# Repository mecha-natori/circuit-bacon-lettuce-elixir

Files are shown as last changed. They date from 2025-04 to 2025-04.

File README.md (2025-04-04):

# Bacon Lettuce Elixir

Bacon Lettuce ElixirはESP32-C3-WROOM-02を使用したBluetooth-USB変換基板です。

USB Type-Aのポートにそのまま差せるため、書き込み・給電が容易です。

## 仕様

| 機能 | 個数 | 備考 |
| :---: | ---: | :--- |
| MCU | 1 | ESP32-C3-WROOM-02 |
| UART | 1 | 電源ピンは5V・外部通信モジュール向け |
| USB Type-A メス | 1 | コントローラー接続用 |
| USB Type-A オス | 1 | 給電・書き込み用 |
| Bluetooth | 1 | MCU内蔵、Bluetooth 5 **(BLEのみ)** |
|  リセットスイッチ | 1 | |
| 5V-3.3Vレギュレータ | 1 | 外部電源からの供給用 |
| 寸法 | | 30mm x 50mm |

## 名前の由来

BLTからトマトが消えてエリクサーになったとさ。 **B**luetooth **L**ow **E**nergyです。

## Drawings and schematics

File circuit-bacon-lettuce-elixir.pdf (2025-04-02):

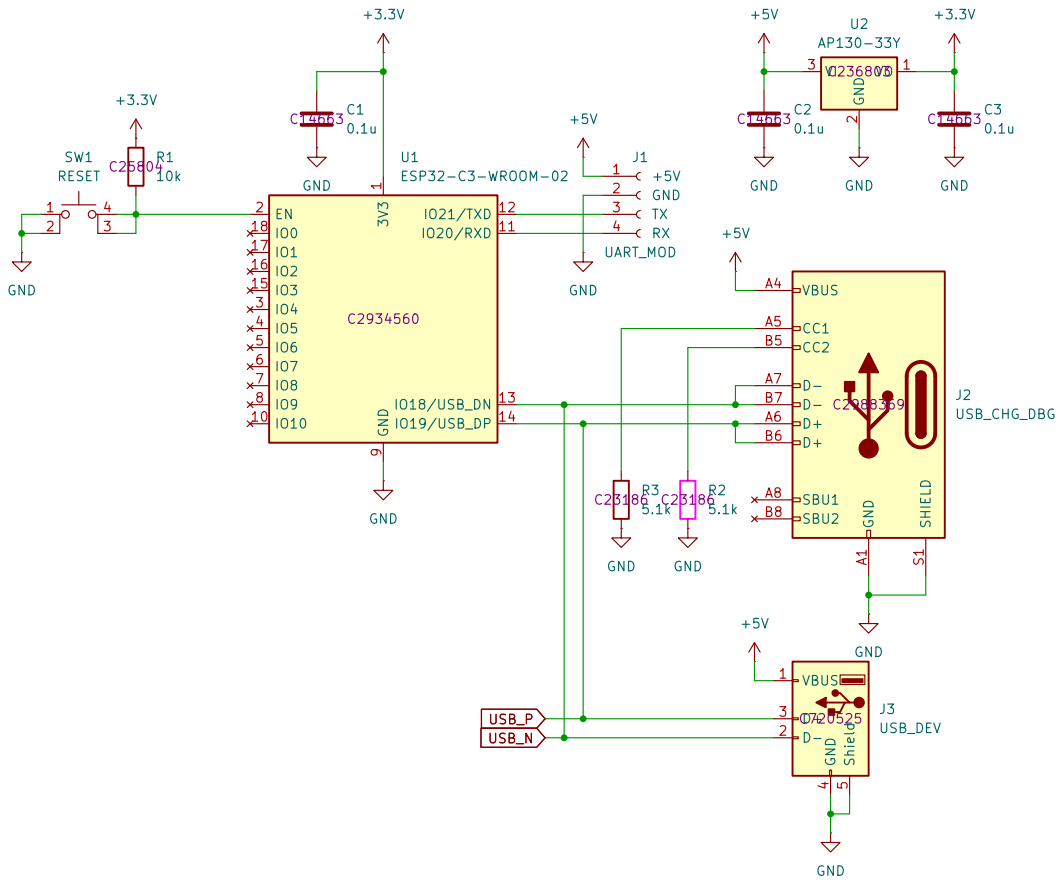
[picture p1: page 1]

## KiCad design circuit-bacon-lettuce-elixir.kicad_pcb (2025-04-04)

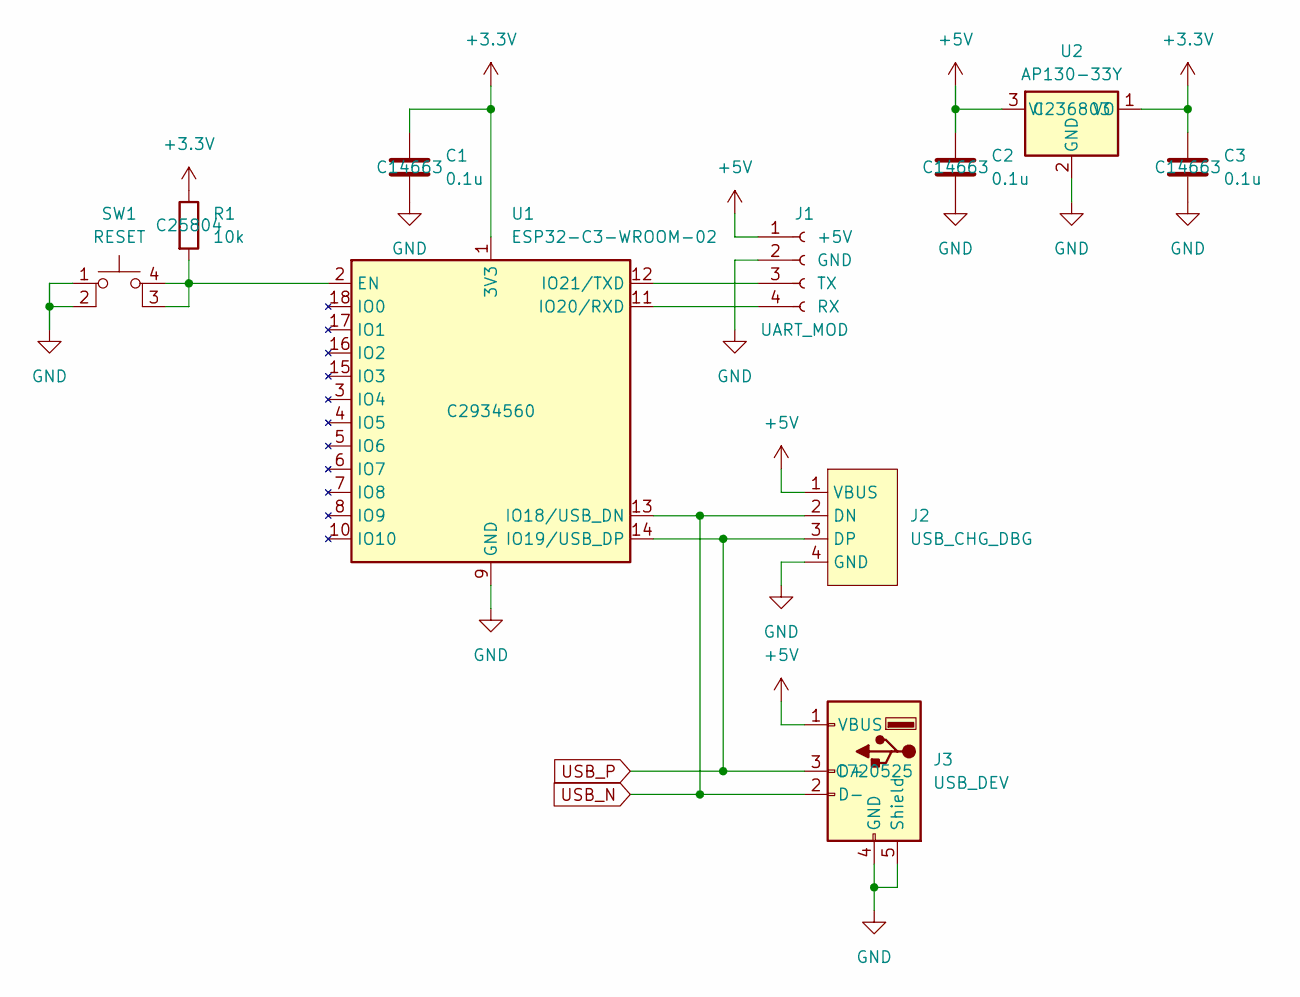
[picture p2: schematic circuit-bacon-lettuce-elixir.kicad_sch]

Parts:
C1, C2, C3: 0.1u; C_0603_1608Metric_Pad1.08x0.95mm_HandSolder; LCSC PN C14663
J1: UART_MOD; DF1B-4P-2.5DSA
J2: USB_CHG_DBG; PCB_USB_Connecter
J3: USB_DEV; USB_A_Receptacle_GCT_USB1046; LCSC PN C720525
R1: 10k; R_0603_1608Metric_Pad0.98x0.95mm_HandSolder; LCSC PN C25804
SW1: RESET; tact
U1: ESP32-C3-WROOM-02; LCSC PN C2934560
U2: AP130-33Y; SOT-89-3; LCSC PN C236803

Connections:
+3.3V: C1.1, C3.1, R1.1, U1.1 (3V3), U2.1 (VO)
+5V: C2.1, J1.1 (+5V), J2.1 (VBUS), J3.1 (VBUS), U2.3 (VI)
GND: C1.2, C2.2, C3.2, J1.2 (GND), J2.4 (GND), J3.4 (GND), J3.5 (Shield), SW1.1, SW1.2, U1.9 (GND), U1.19 (GND), U2.2 (GND)
unnamed: J1.4 (RX), U1.11 (IO20/RXD)
unnamed: J1.3 (TX), U1.12 (IO21/TXD)
unnamed: R1.2, SW1.3 (K), SW1.4 (A), U1.2 (EN)
USB_N: J2.2 (DN), J3.2 (D-), U1.13 (IO18/USB_DN)
USB_P: J2.3 (DP), J3.3 (D+), U1.14 (IO19/USB_DP)

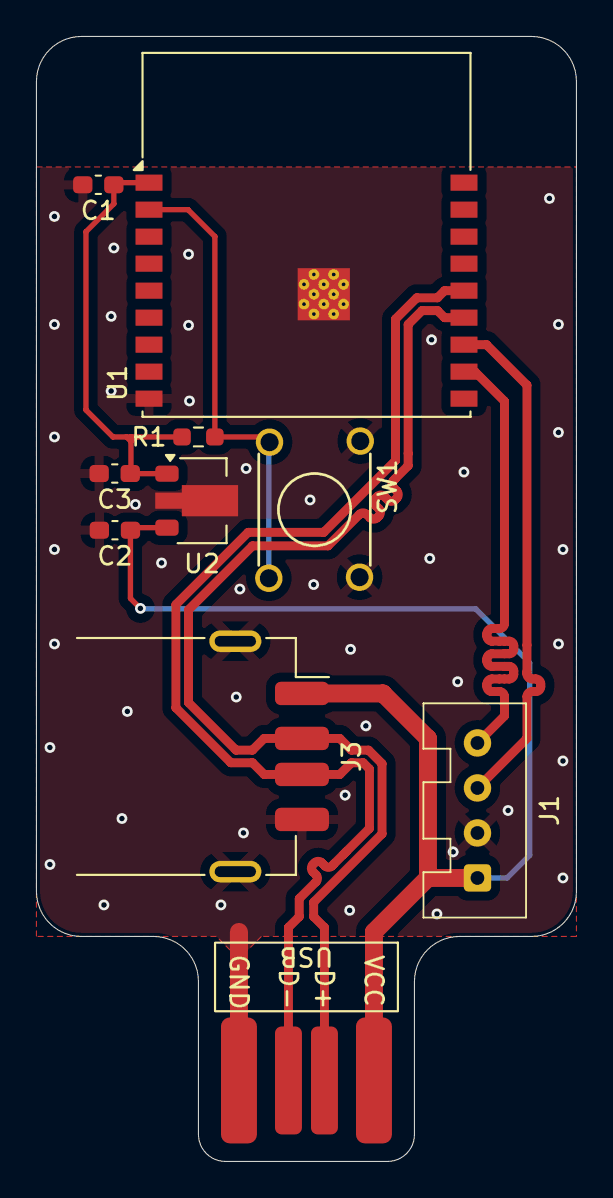
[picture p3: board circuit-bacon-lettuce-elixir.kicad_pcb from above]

Board: 2 copper layers, 30.0 x 62.5 mm, 10 parts (0 on the bottom side), 8 nets.

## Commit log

2025-04-03 feature: ロゴ・リポジトリURLを追加。
    [circuit-bacon-lettuce-elixir.kicad_pcb]
2025-04-04 feature: 書き込み・給電コネクタをType-CからType-Aへ変更。
    [circuit-bacon-lettuce-elixir.kicad_pcb, circuit-bacon-lettuce-elixir.kicad_sch]
